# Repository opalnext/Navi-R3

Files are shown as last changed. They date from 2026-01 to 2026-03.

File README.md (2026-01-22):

# Navi R3

**Navi R3** is a source-available, personal DIY project focused on building a **modular wired + wireless mouse** for makers and light gamers.

The project aims to combine learning, experimentation, and real-world usability, while keeping the hardware open enough for others to extend and customize.

## Project Goals

Navi R3 is designed to:

* Learn and experiment with modern mouse hardware
* Build a mouse that can realistically be used daily
* Provide a clean base platform for custom modules

The project has been actively developed for several months and is currently at a **revision 3 (R3)** hardware stage.

## Hardware Overview

### Core Components

* **MCU**: Nordic nRF52820
* **Optical sensor**: PixArt PMW3360
* **Connectivity**:

  * USB (wired mode)
  * Bluetooth Low Energy (wireless)
* **Battery**: 1S Li-Po
* **Charging**: On-board Li-Ion charger
* **Switches**: Omron D2FC-7-N
* **Scroll wheel**: Mechanical quadrature encoder
* **USB**: USB-C
* **RF**: 2.4 GHz antenna (PCB or external)

The PCB is designed to be simple and focused, without unnecessary integrated features.

## Modular System

Navi R3 includes an optional **modular expansion system**.

* The base PCB exposes GPIO pins intended for external modules
* Side buttons are already connected through this system
* Modules can be both **electronic and mechanical**

Examples of possible modules:

* Additional buttons
* Alternative side button layouts
* Encoders or wheels
* LEDs or RGB indicators

The base PCB itself remains minimal; extra functionality is expected to come from modules.

## Project status

| Feature  | Detail | Status |
|---|---|---|
| Firmware | Readability first, hoping to be speed focused | ❌ |
| Testing  | Test all features | ❌|
| Full release | Entire project available to explore | ❌ | 

❌: Not started
⚠️: Currently working on
✅: Feature

### Wireless roadmap

* Current focus: **BLE**
* Planned later: **custom 2.4 GHz dongle**
* OTA updates are **not implemented**, but could be considered in the future

## Project Status

* Hardware: R3 PCB, not fully tested yet but expected to be functional
* Firmware: under active development
* Modules: concept defined, ecosystem expected to grow over time

This revision of the project has been evolving for about 4 months.

## Manufacturing

* PCB: small-batch friendly, not hand-solderable
* Assembly: DIY or PCBA
* Shell: FDM 3D printed (PLA / PETG)

## License

Navi R3 is **source-available**.

* Source code and hardware files can be viewed and modified
* Forks and personal modifications are allowed
* **Commercial use is not permitted without explicit permission**

Please read the license file carefully before using the project.

## Disclaimer

This is an experimental personal project.
It is provided as-is, without warranty, and may change at any time.

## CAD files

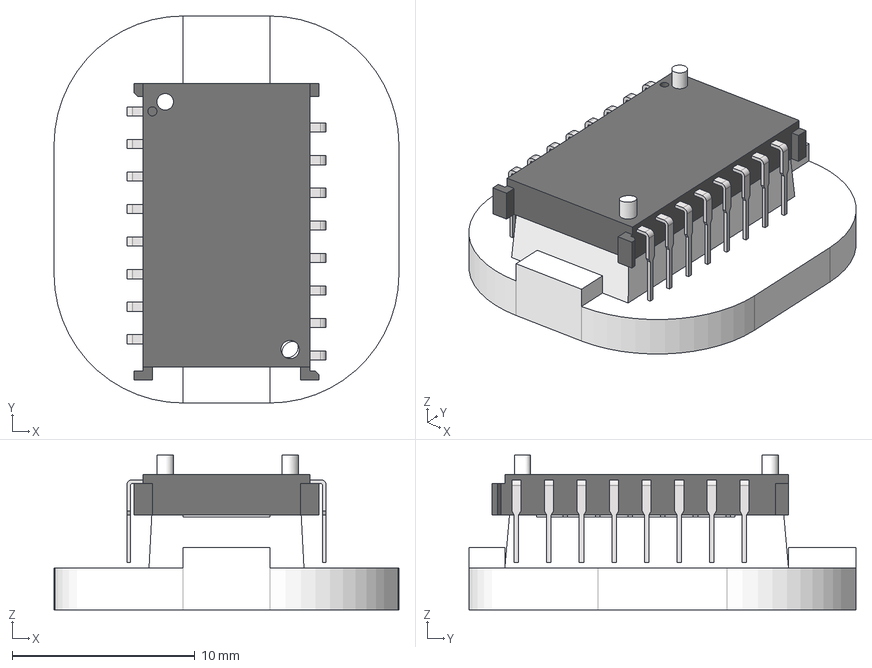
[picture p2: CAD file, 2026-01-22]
3D/PMW3360 v12.step
18.9 x 21.1 x 8.46 mm
Lead x 8
Lead(Mirror) x 8
Lens

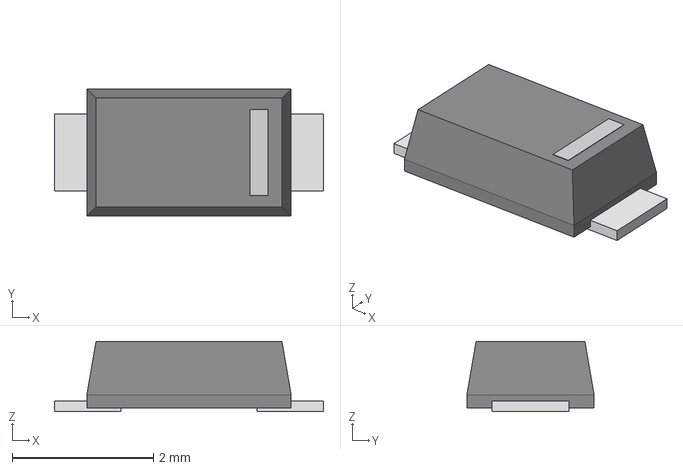
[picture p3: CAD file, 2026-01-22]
3D/SDO_SOD-123FL_ONS.step
3.81 x 1.80 x 0.997 mm

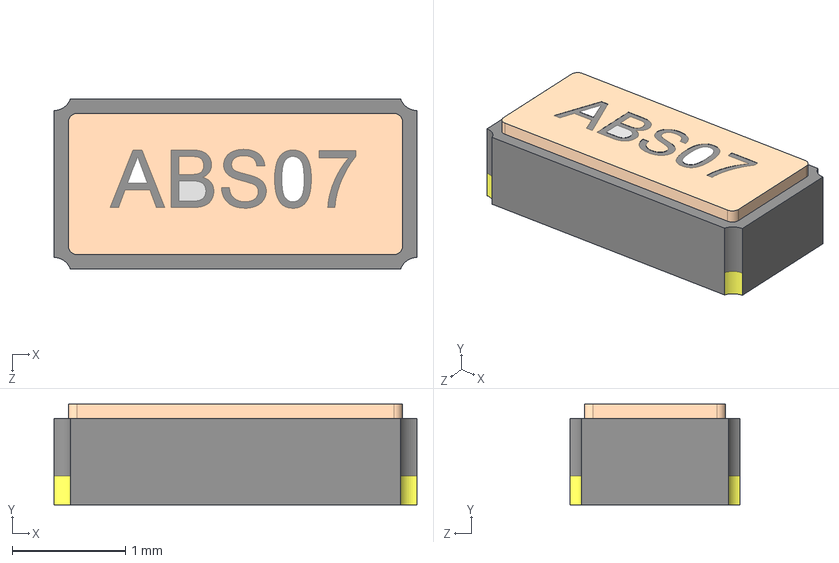
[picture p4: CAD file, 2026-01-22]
3D/ABS07-32.768KHZ-T--3DModel-STEP-400430.STEP
3.20 x 0.889 x 1.50 mm

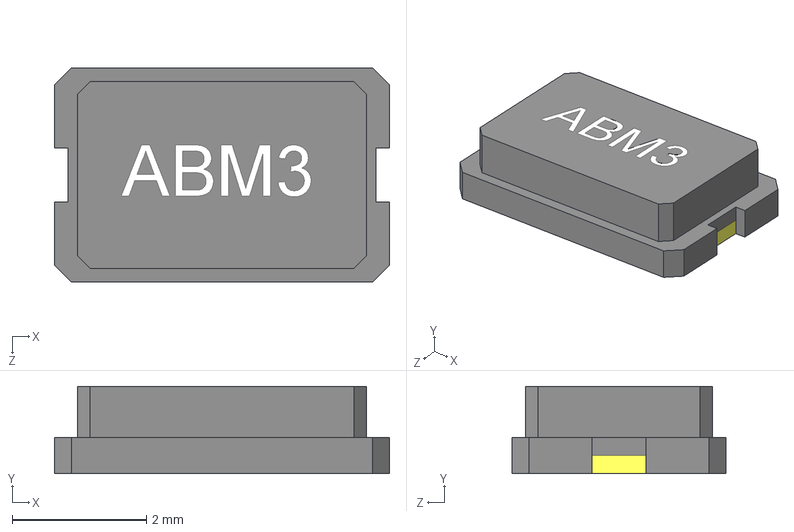
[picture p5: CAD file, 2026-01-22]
3D/ABM3-32.000MHZ-D2Y-T--3DModel-STEP-400430.STEP
5.00 x 1.30 x 3.20 mm

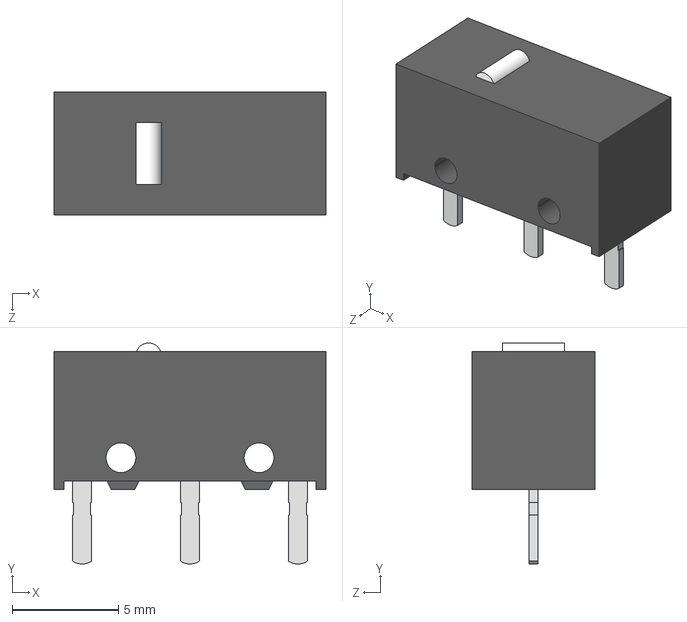
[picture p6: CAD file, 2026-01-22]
3D/D2FC_F_7N_20M.step
12.8 x 10.4 x 5.80 mm
D2FC_F_7N_20M_BUTTON
D2FC_F_7N_20M_BASE

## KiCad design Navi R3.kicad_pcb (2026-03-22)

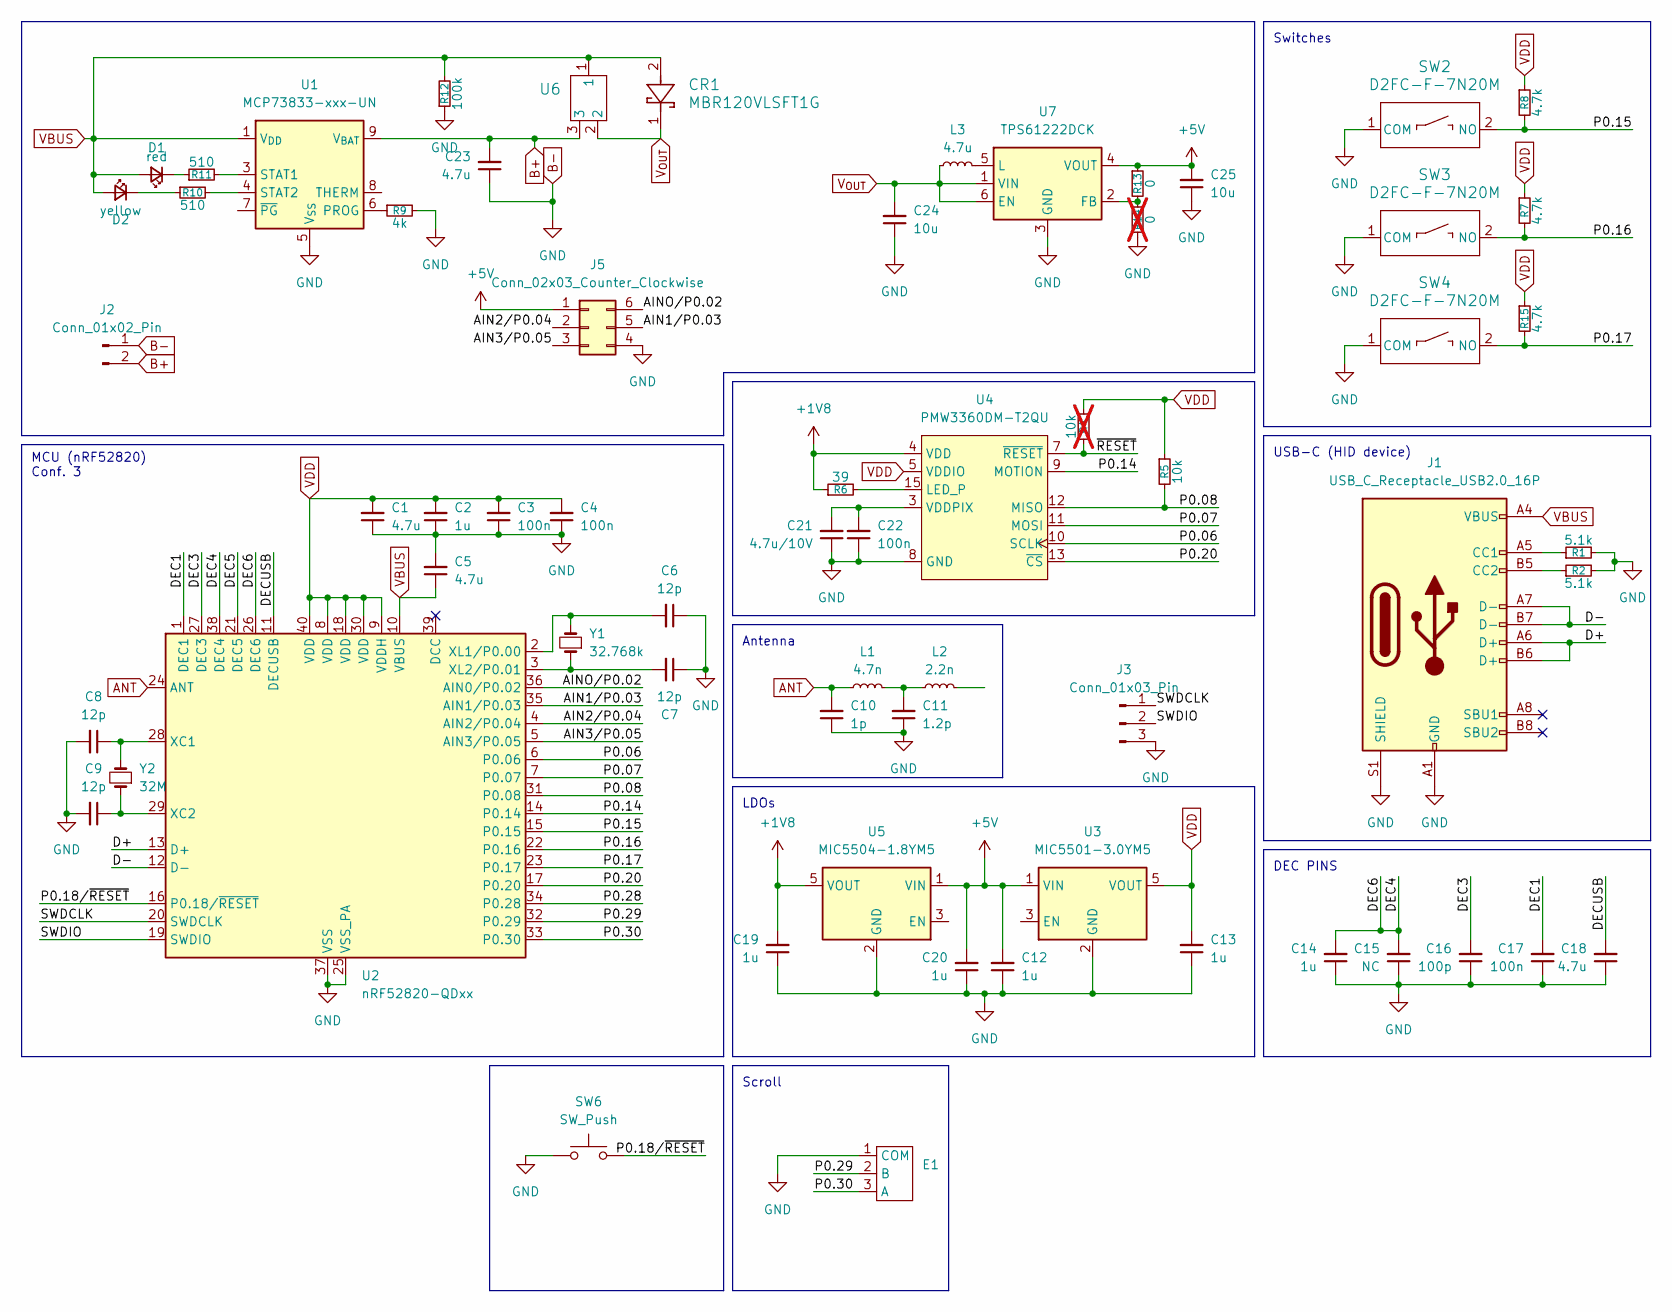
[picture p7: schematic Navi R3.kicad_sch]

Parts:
C1, C5, C18, C23: 4.7u; C_0402_1005Metric
C2, C12, C13, C14, C19, C20: 1u; C_0402_1005Metric
C3, C4, C17, C22: 100n; C_0402_1005Metric
C6, C7, C8, C9: 12p; C_0402_1005Metric
C10: 1p; C_0402_1005Metric
C11: 1.2p; C_0402_1005Metric
C15: NC; C_0402_1005Metric
C16: 100p; C_0402_1005Metric
C21: 4.7u/10V; C_0402_1005Metric
C24, C25: 10u; C_0402_1005Metric
CR1: MBR120VLSFT1G
D1: red; LED_0805_2012Metric
D2: yellow; LED_0805_2012Metric
E1: TTC_Gold
J1: USB_C_Receptacle_USB2.0_16P; USB_C_Receptacle_GCT_USB4105-xx-A_16P_TopMnt_Horizontal
J2: Conn_01x02_Pin; JST_PH_B2B-PH-K_1x02_P2.00mm_Vertical
J3: Conn_01x03_Pin; PinHeader_1x03_P2.00mm_Vertical
J5: Conn_02x03_Counter_Clockwise; PinHeader_2x03_P1.00mm_Vertical
L1: 4.7n; L_0402_1005Metric
L2: 2.2n; L_0402_1005Metric
L3: 4.7u; L_0402_1005Metric
R1, R2: 5.1k; R_0402_1005Metric
R4: 10k; R_0402_1005Metric; not fitted
R5: 10k; R_0402_1005Metric
R6: 39; R_0402_1005Metric
R7, R8, R15: 4.7k; R_0402_1005Metric
R9: 4k; R_0402_1005Metric
R10, R11: 510; R_0402_1005Metric
R12: 100k; R_0402_1005Metric
R13: 0; R_0402_1005Metric
R14: 0; R_0402_1005Metric; not fitted
SW2, SW3, SW4: D2FC-F-7N20M; D2FC-F-7N
SW6: SW_Push; SW_SPST_B3U-3000P
U1: MCP73833-xxx-UN; MSOP-10_3x3mm_P0.5mm
U2: nRF52820-QDxx; QFN-40-1EP_5x5mm_P0.4mm_EP3.6x3.6mm
U3: MIC5501-3.0YM5; SOT-23-5
U4: PMW3360DM-T2QU
U5: MIC5504-1.8YM5; SOT-23-5
U6: IRLML2244TRPBF
U7: TPS61222DCK; Texas_R-PDSO-G6
Y1: 32.768k; CAP_ABS07-32.768KHZ-T_ABR
Y2: 32M; XTAL_ABM3-32.000MHZ-D2Y-T

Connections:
+1V8: C19.2, R6.1, U4.4 (VDD), U5.5 (VOUT)
+5V: C12.2, C20.2, C25.2, J5.1, R13.1, U3.1 (VIN), U5.1 (VIN), U7.4 (VOUT)
/AIN1/P0.03: J5.5, U2.35 (AIN1/P0.03)
/AIN2/P0.04: J5.2, U2.4 (AIN2/P0.04)
/AIN3/P0.05: J5.3, U2.5 (AIN3/P0.05)
/AINO/P0.02: J5.6, U2.36 (AIN0/P0.02)
/D+: J1.A6 (D+), J1.B6 (D+), U2.13 (D+)
/D-: J1.A7 (D-), J1.B7 (D-), U2.12 (D-)
/DEC1: C17.2, U2.1 (DEC1)
/DEC3: C16.2, U2.27 (DEC3)
/DEC4: C14.2, C15.2, U2.26 (DEC6), U2.38 (DEC4)
/DEC5: U2.21 (DEC5)
/DECUSB: C18.2, U2.11 (DECUSB)
/P0.06: U2.6 (P0.06), U4.10 (SCLK)
/P0.07: U2.7 (P0.07), U4.11 (MOSI)
/P0.08: R5.2, U2.31 (P0.08), U4.12 (MISO)
/P0.14: U2.14 (P0.14), U4.9 (MOTION)
/P0.15: R8.2, SW2.2 (NO), U2.15 (P0.15)
/P0.16: R7.2, SW3.2 (NO), U2.22 (P0.16)
/P0.17: R15.2, SW4.2 (NO), U2.23 (P0.17)
/P0.18/~RESET: SW6.2, U2.16 (P0.18/~RESET)
/P0.20: U2.17 (P0.20), U4.13 (~CS)
/P0.28: U2.34 (P0.28)
/P0.29: E1.2 (B), U2.32 (P0.29)
/P0.30: E1.3 (A), U2.33 (P0.30)
/SWDCLK: J3.1, U2.20 (SWDCLK)
/SWDIO: J3.2, U2.19 (SWDIO)
/~RESET: R4.1, U4.7 (~RESET)
ANT: C10.2, L1.1, U2.24 (ANT)
B+: C23.2, J2.2, U1.9 (V_{BAT}), U1.10 (V_{BAT}), U6.3
B-: C1.1, C2.1, C3.1, C4.1, C5.2, C6.1, C7.1, C8.2, C9.2, C10.1, C11.1, C12.1, C13.1, C14.1, C15.1, C16.1, C17.1, C18.1, C19.1, C20.1, C21.1, C22.1, C23.1, C24.1, C25.1, E1.1 (COM), J1.A1 (GND), J1.A12 (GND), J1.B1 (GND), J1.B12 (GND), J1.S1 (SHIELD), J2.1, J3.3, J5.4, R1.2, R2.2, R9.2, R12.1, R14.2, SW2.1 (COM), SW3.1 (COM), SW4.1 (COM), SW6.1, U1.5 (V_{SS}), U2.25 (VSS_PA), U2.37 (VSS), U2.41 (VSS), U3.2 (GND), U4.8 (GND), U5.2 (GND), U7.3 (GND)
unnamed: C11.2, L1.2, L2.1
unnamed: D1.1 (K), R11.1
unnamed: D2.1 (K), R10.1
unnamed: J1.A5 (CC1), R1.1
unnamed: J1.B5 (CC2), R2.1
unnamed: R9.1, U1.6 (PROG)
unnamed: R11.2, U1.3 (STAT1)
unnamed: R10.2, U1.4 (STAT2)
unnamed: C8.1, U2.28 (XC1), Y2.2
unnamed: C9.1, U2.29 (XC2), Y2.1
unnamed: C6.2, U2.2 (XL1/P0.00), Y1.2
unnamed: C7.2, U2.3 (XL2/P0.01), Y1.1
unnamed: R6.2, U4.15 (LED_P)
unnamed: C21.2, C22.2, U4.3 (VDDPIX)
unnamed: R13.2, R14.1, U7.2 (FB)
unnamed: L3.2, U7.5 (L)
VBUS: C5.1, CR1.2, D1.2 (A), D2.2 (A), J1.A4 (VBUS), J1.A9 (VBUS), J1.B4 (VBUS), J1.B9 (VBUS), R12.2, U1.1 (V_{DD}), U1.2 (V_{DD}), U2.10 (VBUS), U6.1
VDD: C1.2, C2.2, C3.2, C4.2, C13.2, R4.2, R5.1, R7.1, R8.1, R15.1, U2.8 (VDD), U2.9 (VDDH), U2.18 (VDD), U2.30 (VDD), U2.40 (VDD), U3.5 (VOUT), U4.5 (VDDIO)
V_{OUT}: C24.2, CR1.1, L3.1, U6.2, U7.1 (VIN), U7.6 (EN)

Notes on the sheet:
DEC PINS
Antenna
MCU (nRF52820) Conf. 3
USB-C (HID device)
Switches
LDOs
Scroll

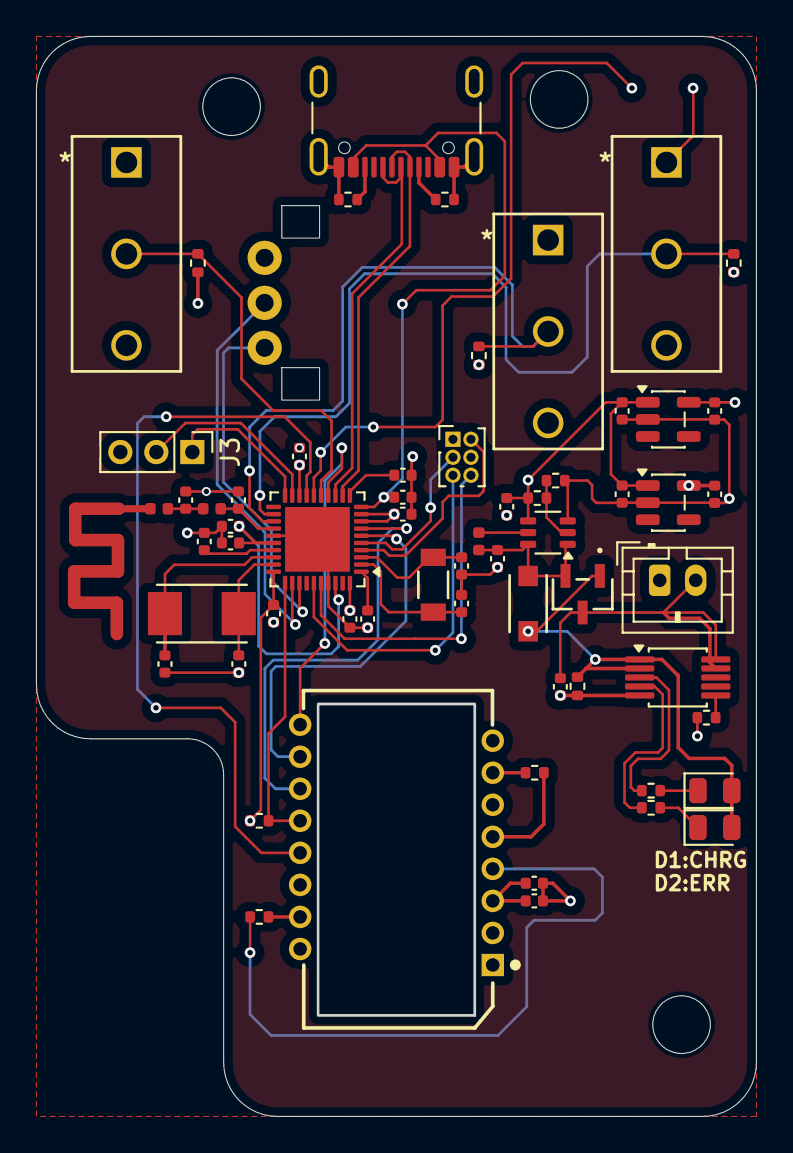
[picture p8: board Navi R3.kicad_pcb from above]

Board: 4 copper layers, 40.0 x 60.0 mm, 64 parts (1 on the bottom side), 48 nets.

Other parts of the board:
B1: Board

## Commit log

2026-03-22 Update SWD headers
    [Navi R3.kicad_pcb, Navi R3.kicad_sch]
2026-03-22 Update rules for DRC
    [Navi R3.kicad_pcb]
